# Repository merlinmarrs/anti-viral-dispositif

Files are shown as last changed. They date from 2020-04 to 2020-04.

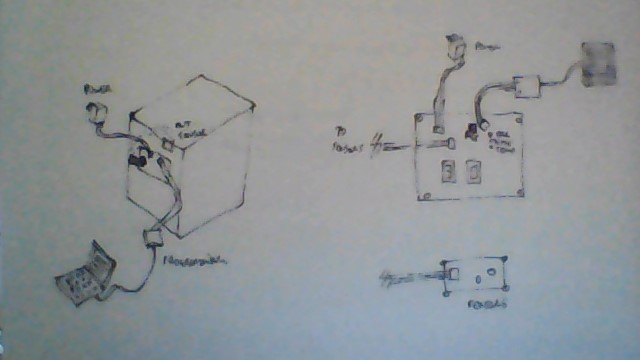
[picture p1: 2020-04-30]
disp desinfect.jpg

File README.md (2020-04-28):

# anti-viral-dispositif

Developed by Fablab Digiscope, France

A main board and secondary board to control a disinfection chamber based on this tutorial: http://www.needlab.org/face-masks-disinfection-device

The PDF shows step by step instructions of the assembly.

Here is the BOM:

Standard components:

7 segment display x2
595 Shift Register x2 
LED x 2
Photocell
Piezo
Atmega 328p
micro-swith (*CHECK MAX VOLT + AMP RATING*)

exotic components:

lampe UV-C à Amazon.fr:

https://www.amazon.fr/Germicide-Ultraviolet-st%C3%A9rilisateur-Submersible-radiations/dp/B07Y82SM36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

2. MLX90614 (pas en rayon a Mouser, Farnell, Sparkfun, Polulu ou
Adafruit) à  Digikey (ou c'est "hors prix") ou Amazon.fr:

https://www.digikey.com/product-detail/en/melexis-technologies-nv/MLX90614ESF-DCA-000-TU/MLX90614ESF-DCA-000-TU-ND/2025323

https://www.amazon.fr/MLX90614ESF-MLX90614ESF-BAA-000-TU-ND-thermom%C3%A8tre-infrarouge-compatible/dp/B07JBKM2K3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

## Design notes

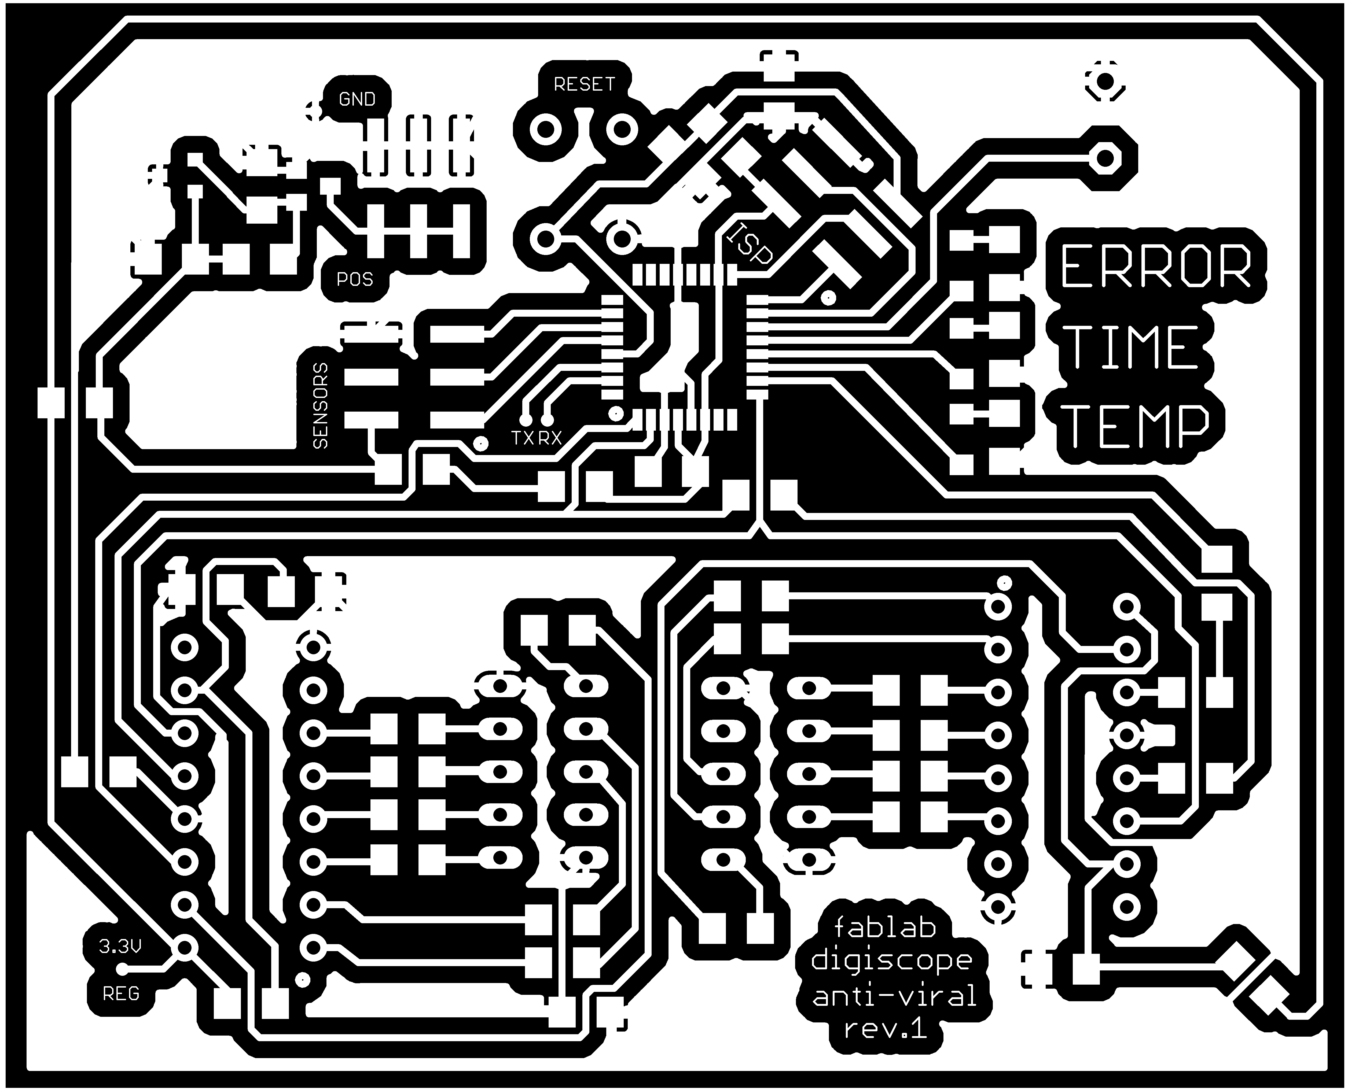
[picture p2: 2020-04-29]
BOARD 1.png

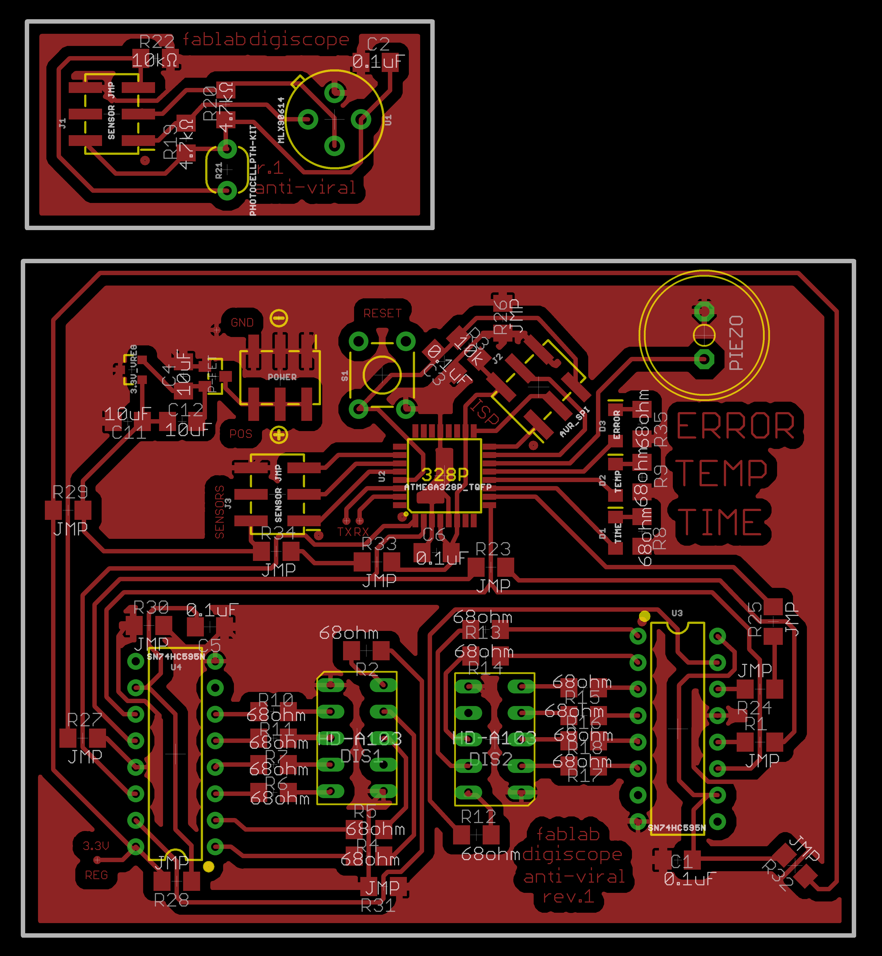
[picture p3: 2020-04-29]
BOARDS W MARKINGS.png

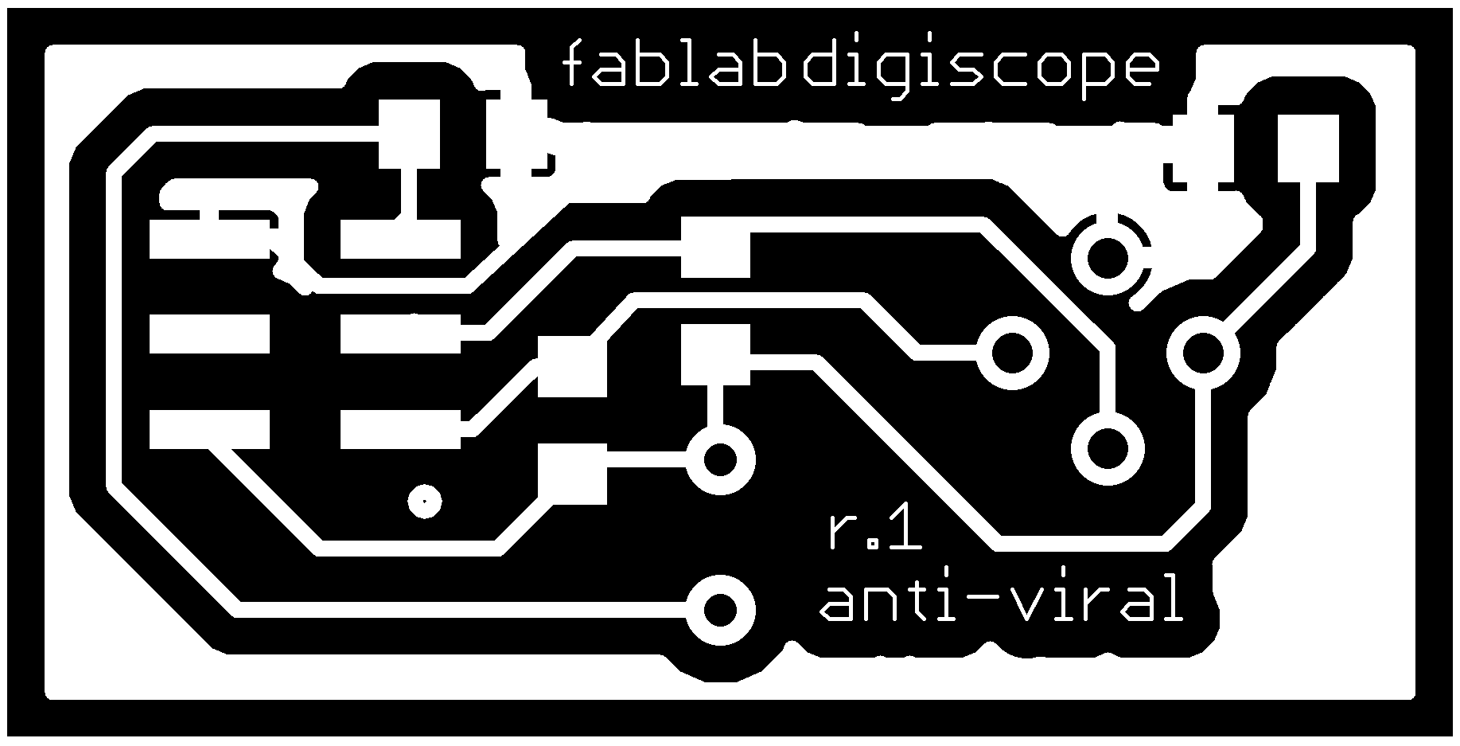
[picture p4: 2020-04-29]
BOARD 2.png

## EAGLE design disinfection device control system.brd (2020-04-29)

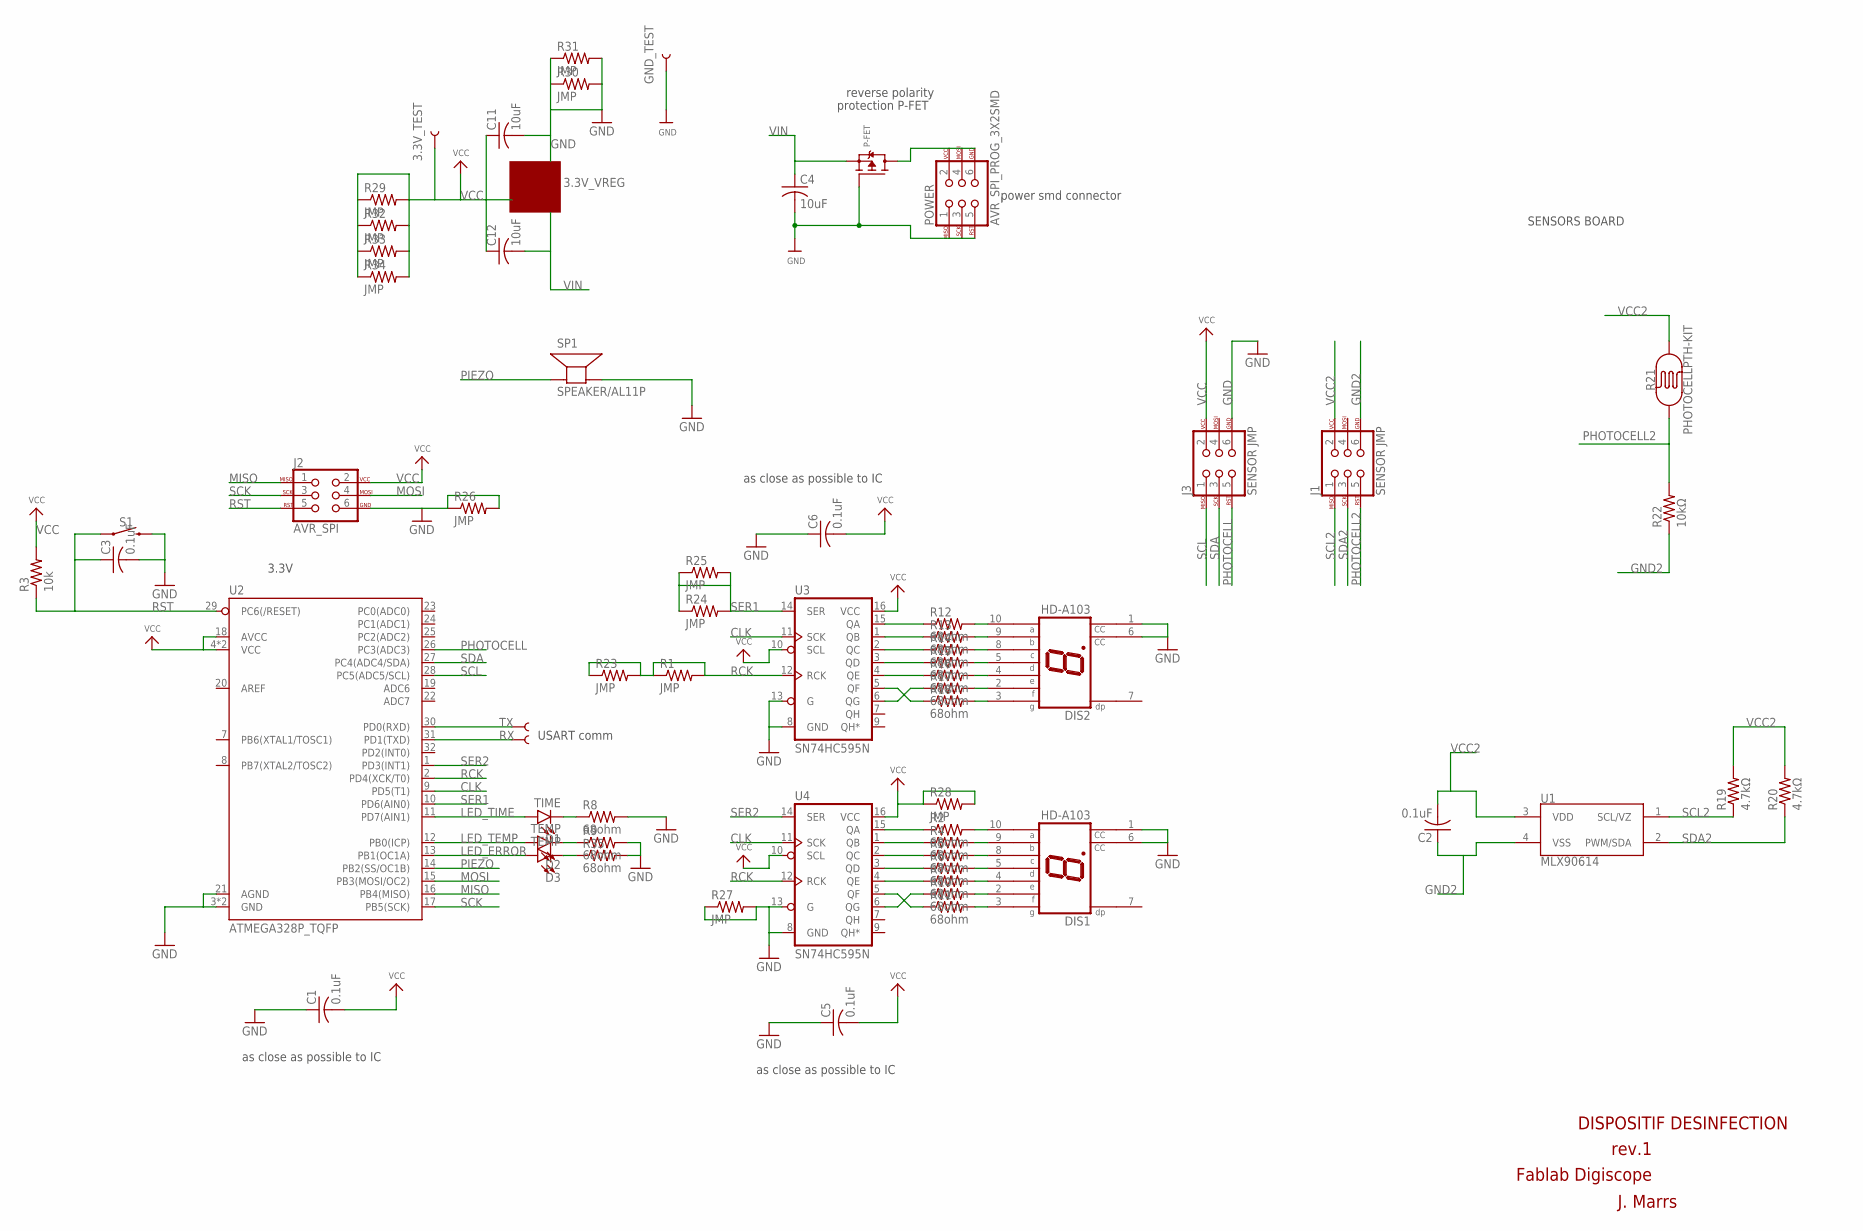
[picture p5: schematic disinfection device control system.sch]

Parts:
3.3V_TEST: TEST-POINT3; PAD.03X.03
3.3V_VREG: MOSFET_PCH-DMG2305UX-7; SOT23-3
C1, C2, C3, C5, C6: 0.1uF; C1206
C4, C11, C12: 10uF; C1206
D1: TIME; LED-1206
D2, D3: TEMP; LED-1206
DIS1, DIS2: HD-A103; HDSP-A
GND_TEST: TEST-POINT3; PAD.03X.03
J1, J3: SENSOR JMP; 2X3_SMT_POSTS
J2: AVR_SPI; 2X3_SMT_POSTS
P-FET: MOSFET-PWIDE; SOT23-WIDE
POWER: AVR_SPI_PROG_3X2SMD; 2X3_SMT_POSTS
R1, R23, R24, R25, R26, R27, R28, R29, R30, R31, R32, R33, R34: JMP; R1206
R2, R4, R5, R6, R7, R8, R9, R10, R11, R12, R13, R14, R15, R16, R17, R18, R35: 68ohm; R1206
R3: 10k; R1206
R19, R20: 4.7kΩ; R1206
R21: PHOTOCELLPTH-KIT; PHOTOCELL-KIT
R22: 10kΩ; R1206
RX: TEST-POINT3; PAD.03X.03
S1: MOMENTARY-SWITCH-SPST-PTH-6.0MM; TACTILE_SWITCH_PTH_6.0MM
SP1: SPEAKER/AL11P; AL11P
TX: TEST-POINT3; PAD.03X.03
U1: MLX90614; TO-39
U2: ATMEGA328P_TQFP; TQFP32-08
U3, U4: SN74HC595N; DIP16

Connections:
CLK: U2.9 (PD5(T1)), U3.11 (SCK), U4.11 (SCK)
GND: 3.3V_VREG.3 (D), C1.1, C3.2, C4.2, C5.1, C6.1, C11.2, DIS1.1 (CC), DIS1.6 (CC), DIS2.1 (CC), DIS2.6 (CC), GND_TEST.P$1, J2.6, J3.6, P-FET.1 (G), POWER.1, POWER.3, POWER.5, R8.2, R9.2, R26.1, R26.2, R27.1, R27.2, R30.1, R30.2, R31.1, R31.2, R35.2, S1.3 (2), SP1.-, U2.3 (GND), U2.5 (GND), U2.21 (AGND), U3.8 (GND), U3.13 (G), U4.8 (GND), U4.13 (G)
GND2: C2.1, J1.6, R22.1, U1.4 (VSS)
LED_ERROR: D3.A, U2.13 (PB1(OC1A))
LED_TEMP: D2.A, U2.12 (PB0(ICP))
LED_TIME: D1.A, U2.11 (PD7(AIN1))
MISO: J2.1, U2.16 (PB4(MISO))
MOSI: J2.4, U2.15 (PB3(MOSI/OC2))
unnamed: DIS1.10 (A), R2.2
unnamed: DIS1.9 (B), R4.2
unnamed: DIS1.8 (C), R5.2
unnamed: DIS1.5 (D), R6.2
unnamed: TX.P$1, U2.30 (PD0(RXD))
unnamed: RX.P$1, U2.31 (PD1(TXD))
unnamed: DIS1.4 (E), R7.2
unnamed: R2.1, U4.15 (QA)
unnamed: R4.1, U4.1 (QB)
unnamed: D2.C, R9.1
unnamed: DIS1.2 (F), R10.2
unnamed: DIS1.3 (G), R11.2
unnamed: R5.1, U4.2 (QC)
unnamed: R6.1, U4.3 (QD)
unnamed: R7.1, U4.4 (QE)
unnamed: R10.1, U4.6 (QG)
unnamed: R11.1, U4.5 (QF)
unnamed: R17.1, U3.6 (QG)
unnamed: R18.1, U3.5 (QF)
unnamed: DIS2.10 (A), R12.2
unnamed: DIS2.9 (B), R13.2
unnamed: DIS2.8 (C), R14.2
unnamed: DIS2.5 (D), R15.2
unnamed: DIS2.4 (E), R16.2
unnamed: DIS2.2 (F), R17.2
unnamed: DIS2.3 (G), R18.2
unnamed: R12.1, U3.15 (QA)
unnamed: R13.1, U3.1 (QB)
unnamed: R14.1, U3.2 (QC)
unnamed: R15.1, U3.3 (QD)
unnamed: R16.1, U3.4 (QE)
unnamed: D3.C, R35.1
PHOTOCELL: J3.5, U2.26 (PC3(ADC3))
PHOTOCELL2: J1.5, R21.1, R22.2
PIEZO: SP1.+, U2.14 (PB2(SS/OC1B))
PWRIN: P-FET.3 (D), POWER.2, POWER.4, POWER.6
RCK: R1.1, R1.2, R23.1, R23.2, U2.2 (PD4(XCK/T0)), U3.12 (RCK), U4.12 (RCK)
RST: C3.1, J2.5, R3.1, S1.1, U2.29 (PC6(/RESET))
SCK: J2.3, U2.17 (PB5(SCK))
SCL: J3.1, U2.28 (PC5(ADC5/SCL))
SCL2: J1.1, R19.1, U1.1 (SCL/VZ)
SDA: J3.3, U2.27 (PC4(ADC4/SDA))
SDA2: J1.3, R20.1, U1.2 (PWM/SDA)
SER1: R24.1, R24.2, R25.1, R25.2, U2.10 (PD6(AIN0)), U3.14 (SER)
SER2: U2.1 (PD3(INT1)), U4.14 (SER)
TIME: D1.C, R8.1
VCC: 3.3V_TEST.P$1, 3.3V_VREG.1 (G), C1.2, C5.2, C6.2, C11.1, C12.1, J2.2, J3.2, R3.2, R28.1, R28.2, R29.1, R29.2, R32.1, R32.2, R33.1, R33.2, R34.1, R34.2, U2.4 (VCC), U2.6 (VCC), U2.18 (AVCC), U3.10 (SCL), U3.16 (VCC), U4.10 (SCL), U4.16 (VCC)
VCC2: C2.2, J1.2, R19.2, R20.2, R21.2, U1.3 (VDD)
VIN: 3.3V_VREG.2 (S), C4.1, C12.2, P-FET.2 (S)

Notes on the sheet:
power smd connector
DISPOSITIF DESINFECTION
rev.1
Fablab Digiscope
J. Marrs
USART comm
as close as possible to IC
reverse polarity
protection P-FET
3.3V
SENSORS BOARD

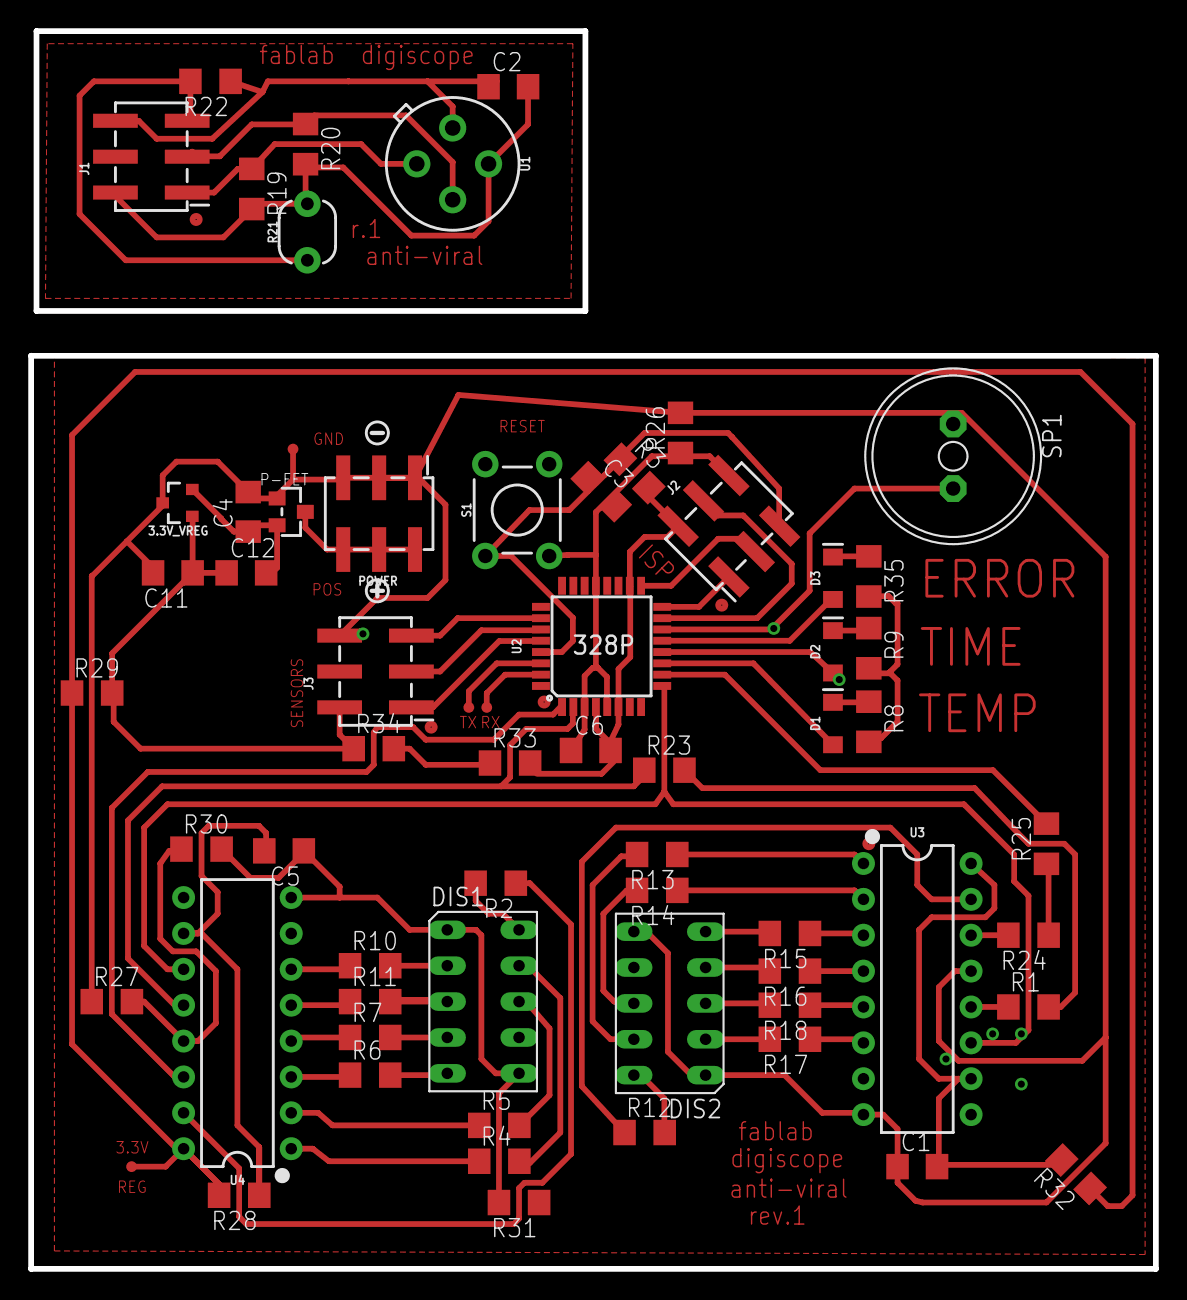
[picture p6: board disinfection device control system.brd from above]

Board: 2 copper layers, 79.6 x 64.6 mm, 66 parts (0 on the bottom side), 57 nets.

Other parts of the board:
U$15: SYMBOL_PLUS
U$16: SYMBOL_MINUS

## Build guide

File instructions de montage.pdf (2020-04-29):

Fab Dispositif Désinfection Rev. 1
instructions de montage

Avec le voltmètre aux probes fines + le microscope, vérifie que les traces adjacentes ne se touchent pas (prends au moins 5 minutes pour bien faire ça)

vérifie que GND et VCC ne sont pas connectés

vérifie que GND partout est relié, et que VCC partout est relié

Pre-Soudage

Soude ces composants pour tester le micro + le processus de télécharger le code

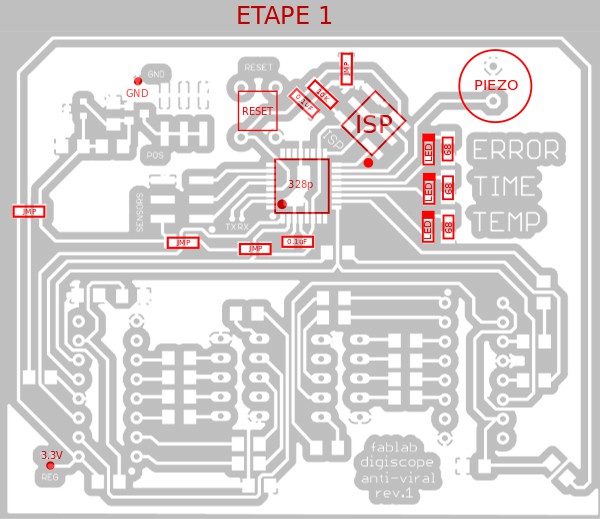
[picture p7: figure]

Branche ISP header + alimente 3.3V ('REG' et 'GND'); Avec AVR Studio, déprogramme fusible CLKDIV=8 (on veux utiliser l'oscillateur interne de 8MHz)

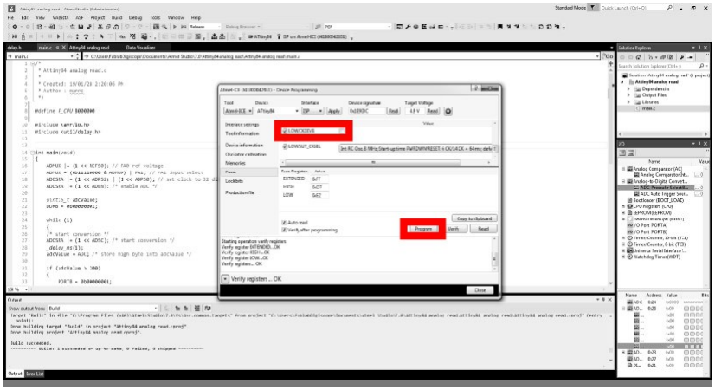
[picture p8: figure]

Ensuite, mets le code C test dans AVR Studio

// Fablab Digiscope //
// Anti-Viral Rev.1 Blink Test Code //
// 04/2020 //

// Target: Atmega 328P //

#define F_CPU 8000000 // I also disable the CLKDIV8 fuse //

#include <avr/io.h>

#include <util/delay.h> // because I'm using _delay_ms() //

int main(void)
{
DDRD = 0b11111111; // All port D pins set to output DDRB = 0b11111111; // All port B pins set to output

while (1) // while value inside the brackets is non-zero, {
PORTD = 0b00000000; //
PORTB = 0b00000010; // ERROR LED ON _delay_ms(1000); //1000ms = 1 second

PORTB = 0b00000000; //
PORTD = 0b10000000; // TIME LED ON _delay_ms(1000); //1000ms = 1 second

PORTD = 0b00000000; //
PORTB = 0b00000001; // TEMP LED ON _delay_ms(1000); //1000ms = 1 second

}
return (0);
}

Clique “Device Programming'

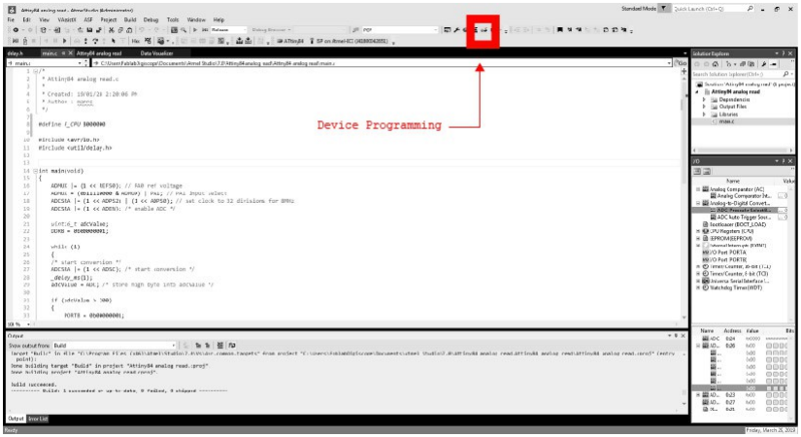
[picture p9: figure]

Selectionne Atmega 328,
Read Voltage, ensuite programme le code C

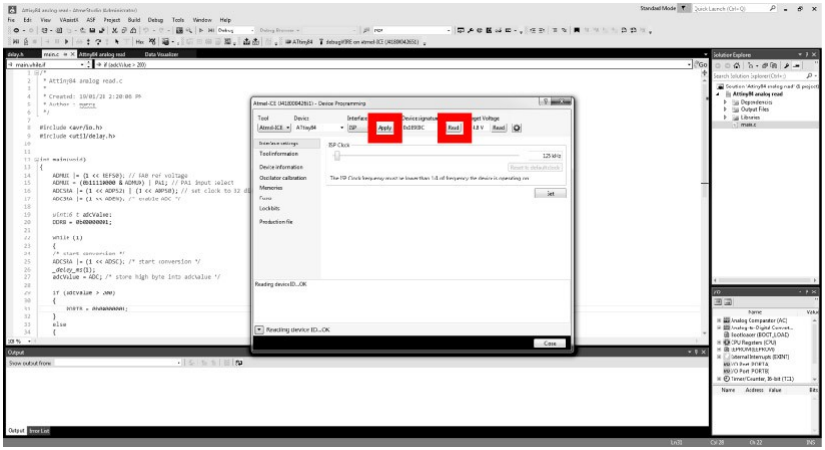
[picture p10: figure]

Est-ce que les trois LED clignotent avec un délai d'une seconde?

Soude les composants pour
l'alimentation

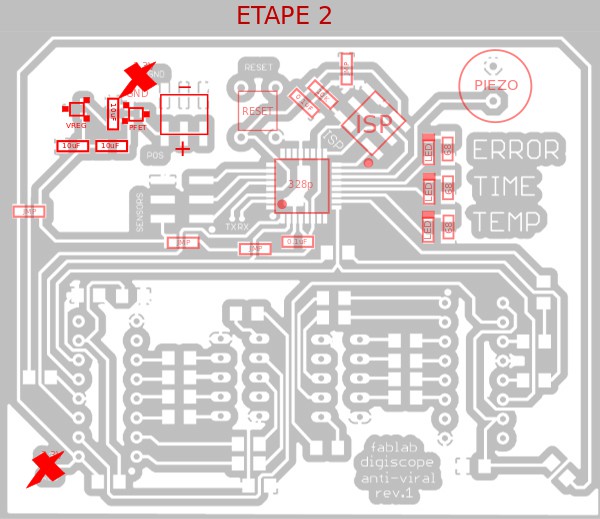
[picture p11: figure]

Alimente avec 5V, est-ce que notre test code fonctionne comme avant?

Est-ce que le test point 'REG' reçoit bien 3.3V?

Soude les composants pour tester les capteurs

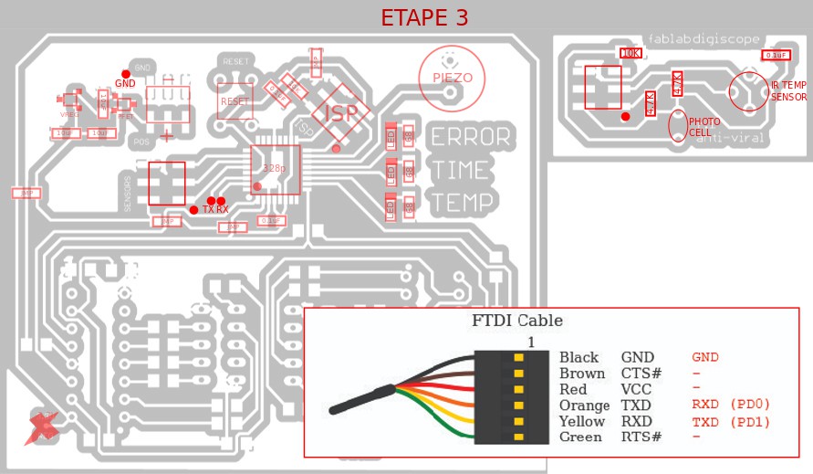
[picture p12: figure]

Branche ISP, alimente; Branche USART; Programme le
photocell_test.hex

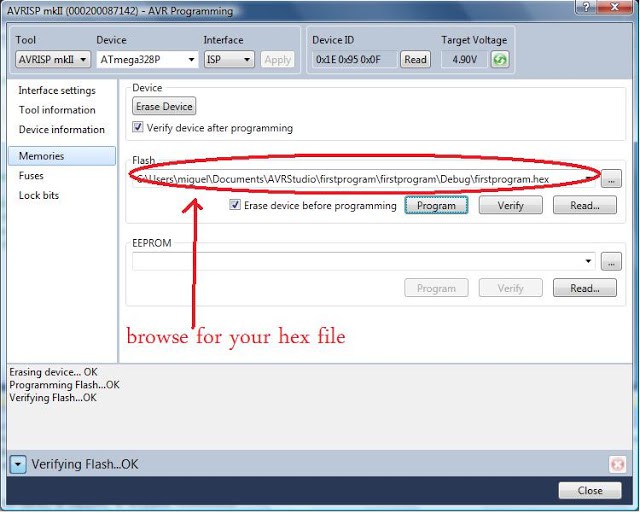
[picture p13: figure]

USART AVEC AVR STUDIO

Tools > Data Visualizer
Configuration > Modules > External Connection > Serial Port
Configure port > Baud Rate = 9600
Choisir port COM
Clique 'Connect'

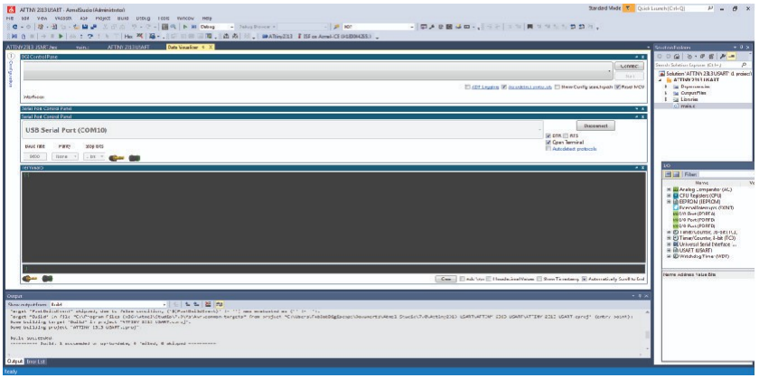
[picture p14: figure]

Est-ce que les changements dans l’intensité de la lumière pour la photocell changent la valeur affichée par le port sériel ?

Branche ISP, alimente; Branche USART; Programme le
tempsensor_test.hex

Est-ce que les changements dans la chaleur pour le capteur de température IR changent la valeur affichée par le port sériel ?

Soude les composants restants

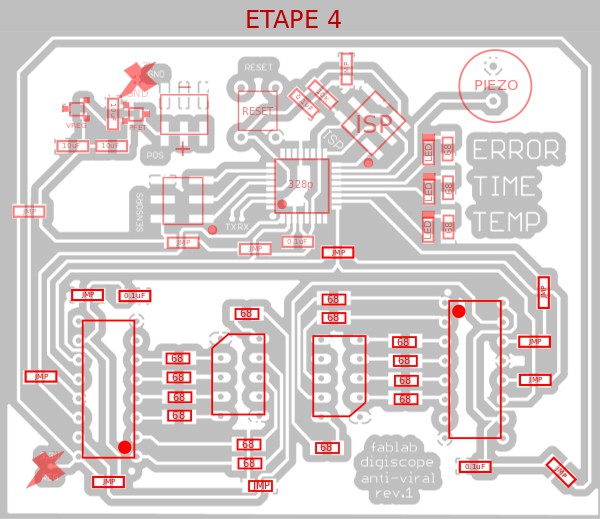
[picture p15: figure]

Branche ISP, alimente; Programme le display_test.hex

Est-ce que les deux 7 seg-displays comptent de 0 à F à leur tour?

Branche ISP, alimente; Programme le light_temp_display_test.hex

Est-ce que la température ambiante est affichée sur les displays ?

Branche ISP, alimente; Programme le full_device_test.hex

Est-ce que tout marche ?

BRAVO!!

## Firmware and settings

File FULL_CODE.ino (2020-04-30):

/*  
 *   
 *   Based on Mel Lester Jr.'s  SevenSegmentLEDdisplay102a.ino 2017-02-20
 *   Fablab Digiscope Display test
 *   Note: F and G on both Displays are switched and there is no decimal point hooked up
 *   
 *   Code to run PCB for this tutorial:
 *   http://www.needlab.org/face-masks-disinfection-device
 *   
*/


#include <Wire.h>
#include <Adafruit_MLX90614.h>

// MLX90614 Temperature Sensor 
Adafruit_MLX90614 mlx = Adafruit_MLX90614();


// GLOBALS

//Piezo
const int piezo = 10; // 

//Photoresistor
const int pResistor = A3; // Photoresistor at Arduino analog pin A3
const int light_threshold = 500; // TEST THIS!

//Shift Register
const int dataPin1 = 3; // left 7 segment display
const int dataPin2 = 6; // right 7 segment display
const int latchPin = 4; // shared between the two shift registers
const int clockPin = 5; // shared between the two shift registers

//LEDs
const int tempLed = 8; // 
const int timeLed = 7; // 
const int errorLed = 9; // 

//Timing
const unsigned long period = 60000;  //the value is a number of milliseconds in a minute

// MLX90614 Temperature Sensor 
const int temp_threshold_min = 70; // 
const int temp_threshold_max = 75; // 

//VARIABLES

//Timing
unsigned long startMillis;  
unsigned long currentMillis;


//Photoresistor
int light;          // Store value from photoresistor (0-1023)

// MLX90614 Temperature Sensor 
int temp;          // Store value from temp sensor



//FUNCTIONS

void myfnUpdateDisplay1(byte eightBits) {

  digitalWrite(latchPin, LOW);  // prepare shift register for data
  shiftOut(dataPin1, clockPin, LSBFIRST, eightBits); // send data
  digitalWrite(latchPin, HIGH); // update display
}

void myfnUpdateDisplay2(byte eightBits) {

  digitalWrite(latchPin, LOW);  // prepare shift register for data
  shiftOut(dataPin2, clockPin, LSBFIRST, eightBits); // send data
  digitalWrite(latchPin, HIGH); // update display
}


byte myfnNumToBits(int someNumber) {
  switch (someNumber) {
    case 0:
      return B11111010;
      break;
    case 1:
      return B01100000;
      break;
    case 2:
      return B11011100;
      break;
    case 3:
      return B11110100;
      break;
    case 4:
      return B01100110;
      break;
    case 5:
      return B10110110;
      break;
    case 6: 
      return B10111110;
      break;
    case 7:
      return B11100000;
      break;
    case 8:
      return B11111110;
      break;
    case 9:
      return B11110110;
      break;
    case 10:
      return B11101110; // Hexidecimal A
      break;
    case 11:
      return B00111110; // Hexidecimal B
      break;
    case 12:
      return B10011010; // Hexidecimal C or use for Centigrade
      break;
    case 13:
      return B01111100; // Hexidecimal D
      break;
    case 14: 
      return B10011110; // Hexidecimal E
      break;
    case 15:
      return B10001110; // Hexidecimal F or use for Fahrenheit
      break;  
    default:
      return B10010100; // Error condition, displays three vertical bars
      break;   
  }
}

void Display(int value) {

//    int trunc_value = (int) value; //truncate to just whole numbers
    
    int j = value / 10; //look at the second number before the decimal point  

    byte bits1 = myfnNumToBits(j);
    myfnUpdateDisplay1(bits1);    // display 2nd alphanumeric digit on left display

    int i = value % 10; //look at the first number before the decimal point

    byte bits2 = myfnNumToBits(i); //
    myfnUpdateDisplay2(bits2);    // display 1st alphanumeric digit on right display
    
    delay(10);                 // pause 
}


void Fin(void){

  for (int i; i++; i<10) // blink temp LED while beeping 10 times
  {
  tone(piezo, 500); // format: pin, hertz, millis
  digitalWrite(errorLed, LOW); // Error LED on
  digitalWrite(tempLed, LOW); // 
  digitalWrite(timeLed, HIGH); // 
  delay(500);
  noTone(piezo);
  digitalWrite(timeLed, LOW); // 
  delay(500);
  }
}

void TempWait(void){

  temp = mlx.readAmbientTempC(); // read temp sensor ambiant. Also possible to read object temp with mlx.readObjectTempC()
    
  while(temp < temp_threshold_min) // while we're below the temp threshold, display the temp
  {
    digitalWrite(tempLed, HIGH); // Temp LED on
    digitalWrite(errorLed, LOW); // 
    digitalWrite(timeLed, LOW); // 
    
    Display(temp);
  }
}


void Count(void)
{
   tone(piezo, 500, 1000); // format: pin, hertz, millis. Buzz one sec to signal start of timing
   
   int Minutes; // Minutes to display
   startMillis = millis();  //initial start time

   temp = mlx.readAmbientTempC(); // read temp sensor ambiant. Also possible to read object temp with mlx.readObjectTempC()
   light = analogRead(pResistor); // read photo resistor
   
   if(temp > temp_threshold_min && temp < temp_threshold_max && light > light_threshold && Minutes < 30) // while in the correct range and light is on
   {
    //display time LED
    digitalWrite(timeLed, HIGH); // Time LED on
    digitalWrite(errorLed, LOW); // 
    digitalWrite(tempLed, LOW); // 

      currentMillis = millis();  //get the current "time" (actually the number of milliseconds since the program started)
      if (currentMillis - startMillis >= period)  //test whether the period has elapsed
      {
        //increment minute counter and display
        Minutes++;
        Display(Minutes);
        startMillis = currentMillis;  //IMPORTANT to save the start time
      }
        
   }

    else if(temp > temp_threshold_min && temp < temp_threshold_max && light > light_threshold && Minutes >= 30) // 30 minutes have elapsed
    {
      Fin();
    }
     
   else
   {
    Error();
   }
}


void Error(void){
  
    for (int i; i++; i<10) // blink temp LED while beeping 10 times
    {
    tone(piezo, 1000, 1000); // format: pin, hertz, millis
    
    digitalWrite(errorLed, HIGH); // Error LED on
    digitalWrite(tempLed, LOW); // 
    digitalWrite(timeLed, LOW); // 
    
    myfnUpdateDisplay2(B10010100);  //three bars = error
    myfnUpdateDisplay1(B10010100);  //three bars = error
    }
}




void setup() {
  // INITS

  //Piezo
  pinMode(piezo, OUTPUT);

  //LEDs
  pinMode(timeLed, OUTPUT);
  pinMode(tempLed, OUTPUT);
  pinMode(errorLed, OUTPUT);
  
  // Shift Register
  pinMode(dataPin1, OUTPUT);
  pinMode(dataPin2, OUTPUT);
  pinMode(latchPin, OUTPUT);
  pinMode(clockPin, OUTPUT);

  // Photocell 
  pinMode(pResistor, INPUT);// Set pResistor - A3 pin as an input

  // MLX90614 Temperature Sensor - communicates via I2C
  mlx.begin();  
}

void loop() {

  TempWait(); // wait for temp to hit 70 C
  Count(); // begin 30 minute timer
  Fin(); // 30 minutes has elapsed, sound buzzer
  
}

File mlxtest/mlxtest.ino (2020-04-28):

/*************************************************** 
  This is a library example for the MLX90614 Temp Sensor

  Designed specifically to work with the MLX90614 sensors in the
  adafruit shop
  ----> https://www.adafruit.com/products/1747 3V version
  ----> https://www.adafruit.com/products/1748 5V version

  These sensors use I2C to communicate, 2 pins are required to  
  interface
  Adafruit invests time and resources providing this open source code, 
  please support Adafruit and open-source hardware by purchasing 
  products from Adafruit!

  Written by Limor Fried/Ladyada for Adafruit Industries.  
  BSD license, all text above must be included in any redistribution
 ****************************************************/

#include <Wire.h>
#include <Adafruit_MLX90614.h>

Adafruit_MLX90614 mlx = Adafruit_MLX90614();

void setup() {
  Serial.begin(9600);

  Serial.println("Adafruit MLX90614 test");  

  mlx.begin();  
}

void loop() {
  Serial.print("Ambient = "); Serial.print(mlx.readAmbientTempC()); 
  Serial.print("*C\tObject = "); Serial.print(mlx.readObjectTempC()); Serial.println("*C");
  Serial.print("Ambient = "); Serial.print(mlx.readAmbientTempF()); 
  Serial.print("*F\tObject = "); Serial.print(mlx.readObjectTempF()); Serial.println("*F");

  Serial.println();
  delay(500);
}

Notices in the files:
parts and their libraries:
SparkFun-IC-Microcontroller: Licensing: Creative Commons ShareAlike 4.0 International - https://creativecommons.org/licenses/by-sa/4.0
